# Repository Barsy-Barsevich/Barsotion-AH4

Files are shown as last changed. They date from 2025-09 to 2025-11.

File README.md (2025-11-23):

# AH4: ICM-45686 devboard
the 12th board after Berkut

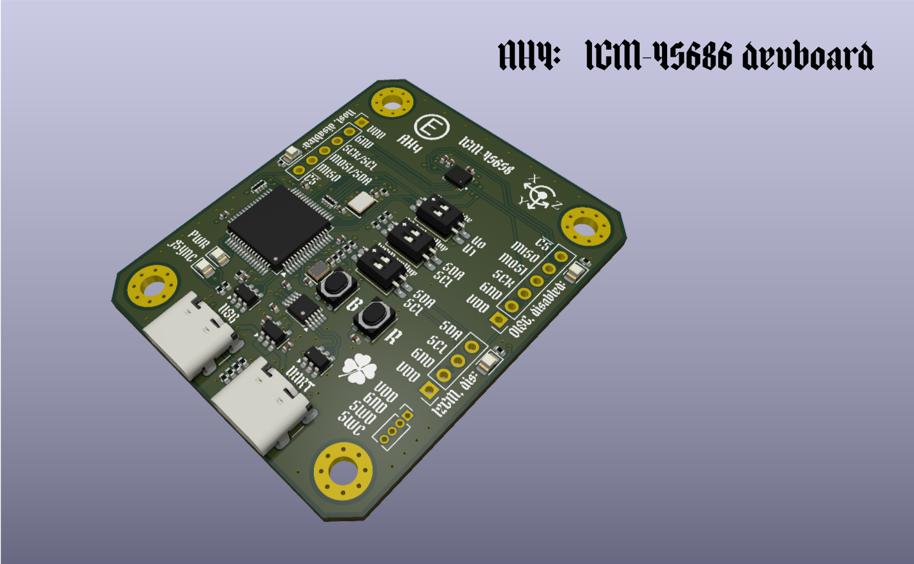
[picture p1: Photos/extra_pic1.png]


---
## ⚡️Abstract
Development board for ICM-45686 InvenSense TDK gyroscope & accelerometer. You can connect to it's interfaces (AP, OIS, I2CM) or drive them by on-board CH32V305RBT6 microcontroller.

- All ICM-45686 interfaces are routed (AP, OIS, I2CM);
- AP interface can be I2C or SPI
- On-board 32.768 kHz quartz oscillator to stabilize ODR frequency;
- On-board 32-bit RISC-V MCU to simplify ICM-45686 research;
- USB 2.0 HS and USB-UART are routed from the MCU.

---
## ⚡️Continious progress
- [Previous board: Barsotion-TA](https://github.com/Barsy-Barsevich/Barsotion-TA)
- [Previous board: Barsotion-PL1](https://github.com/Barsy-Barsevich/Barsotion-PL1)

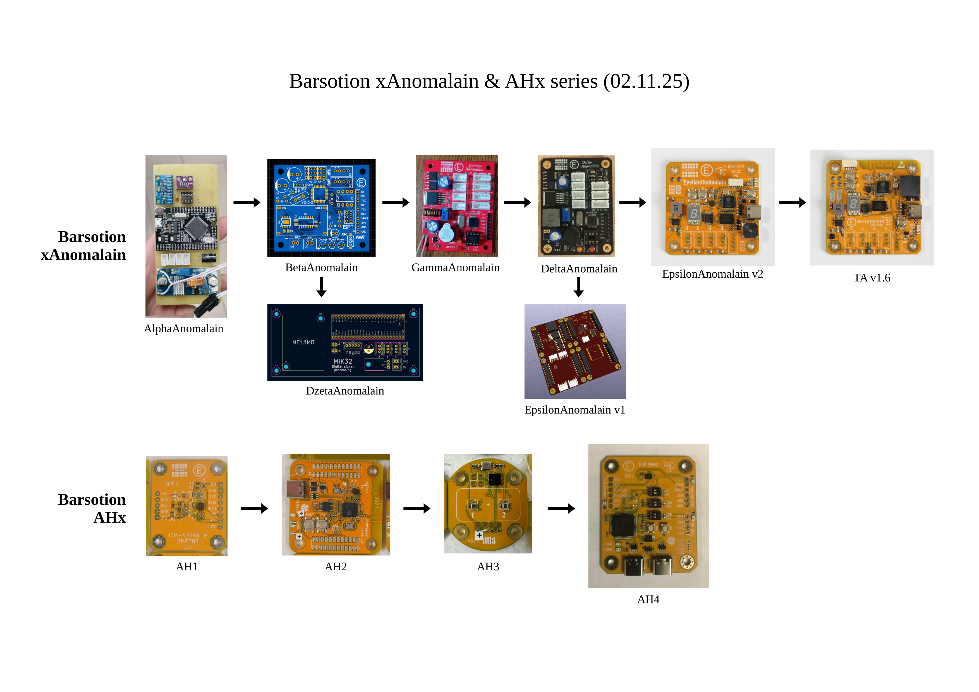
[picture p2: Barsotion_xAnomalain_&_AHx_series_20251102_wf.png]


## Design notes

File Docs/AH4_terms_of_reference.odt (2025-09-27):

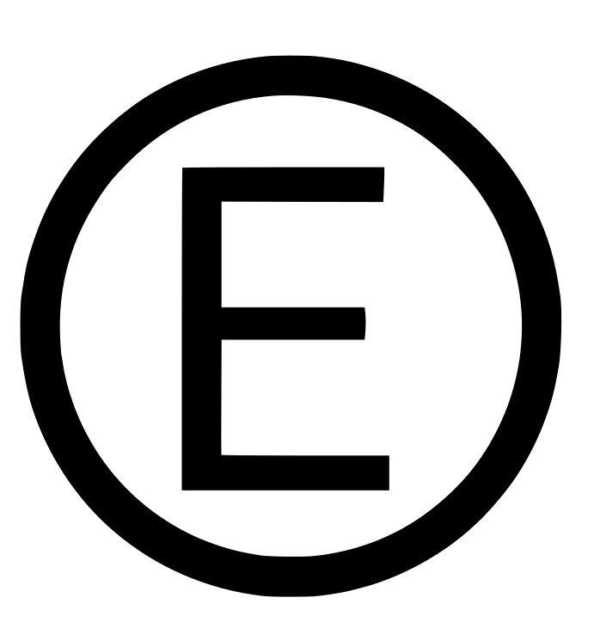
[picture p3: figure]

Barsotion AH4:

Terms of reference

## Abstract

This document is purposed to describe terms of reference of the perspective Barsotion development board AH4.

The AH4 (herein the board) is a project of development board for the TDK InvenSense ICM-45686, IMU (i.e. gyroscope & accelerometer) that has the best parameters in the world today, also allowing to measure linear accelerations up to 32g and angle velocities up to 4000 degrees per second.

The board is creating to develop ICM-45686 capabilities. It should contain the IMU & the microcontroller to research sensor features within one PCB.

## Main points

### The board should contain

- ICM-45686 IMU (gyroscope & accelerometer);
- Quartz oscillator 32-40 kHz for IMU ODR frequency stabilization;
- A modern 32-bit microcontroller at frequency not less than 100 MHz, having hardware floating-point unit (FPU) and USB 2.0 High-speed interface (supposedly CH32V305xxx);
- Reset button;
- 2x USB-C connector;
- “Tag-connect” connector for microcontroller flashing;
- USB-UART converter to link microcontroller even if USB-HS topology is failed;
- DIP-switch, 2 switches to lay 4 scenarios of working;
- 2 signal leds, yellow color, connected to DIP-switch;
- Power led, yellow color, to indicate powering;
- 3 signal leds, red color, connected to microcontroller;
- Signal led, yellow color, connected to microcontroller;
- Low-dropout (LDO) voltage regulator, 3.3V (supposedly AP2112-3.3).

### IMU connection

The ICM-45686 has three external interfaces:

- Host interface (SPI, I2C, I3C) to link with the microcontroller (host);
- Optical Image Stabilization Controller (OISC) interface (SPI);
- I2C master interface (I2CM).

The board should allow user to test all the ICM-45686 interfaces. According the datasheet, only one of OIS & I2CM interfaces can be used in moment. Supposedly the board schematic should link host & OIS interfaces directly to two hardware SPI ports of the microcontroller. Also, the host I2C interface should be connected to microcontroller’s I2C pins. Host interface (supporting SPI & I2C) should be routed to PLS connector. OIS and I2CM interfaces should be routed to individual PLS connectors.

The interrupt channels should be routed to the microcontroller.

The ODR syncronizing signal should be routed to the IMU pin via transistor controlled by microcontroller.

### PCB requirements

- The PCB should have at less 4 mounting holes;
- Should include designations for all the board connectors;
- The board silkscreen should contain warning that only one of OIS & I2CM interfaces can be activated at moment;
- Signal leds should indicate enabling microcontroller’s working with IMU host, OIS & I2CM interfaces.

## Revision history

Date | Modification
Aug 19, 2025 | Document’s first release.

Barsotion AH4: CONFIDENTIAL BARSOTIONTerms of reference

CONFIDENTIAL BARSOTION

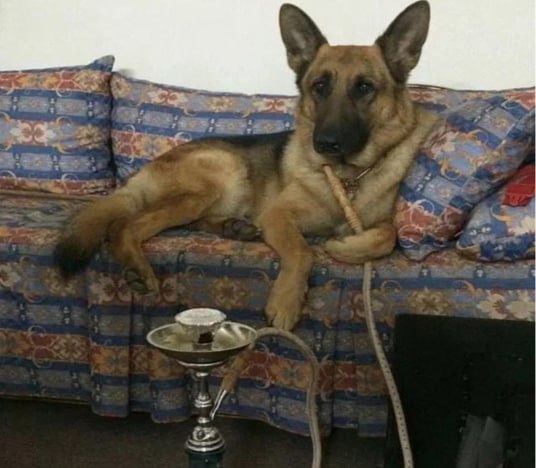
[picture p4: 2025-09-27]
totem.jpg

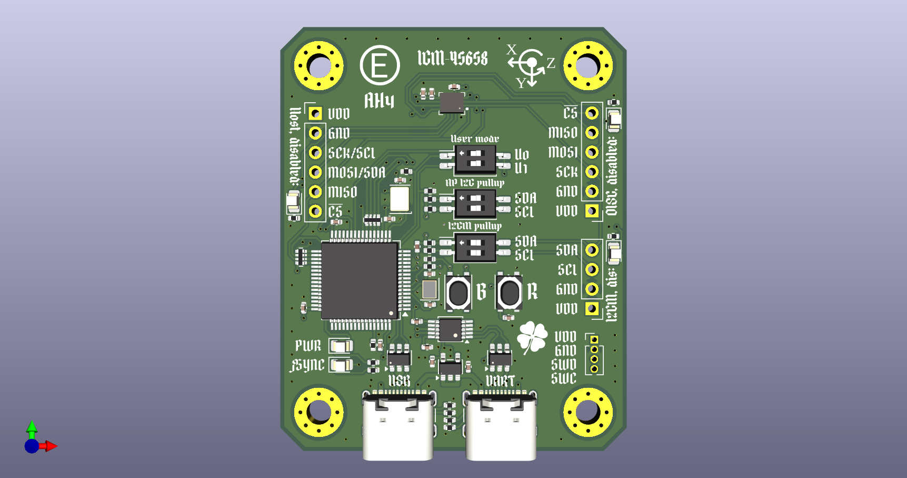
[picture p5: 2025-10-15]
Photos/AH4_pic5.png

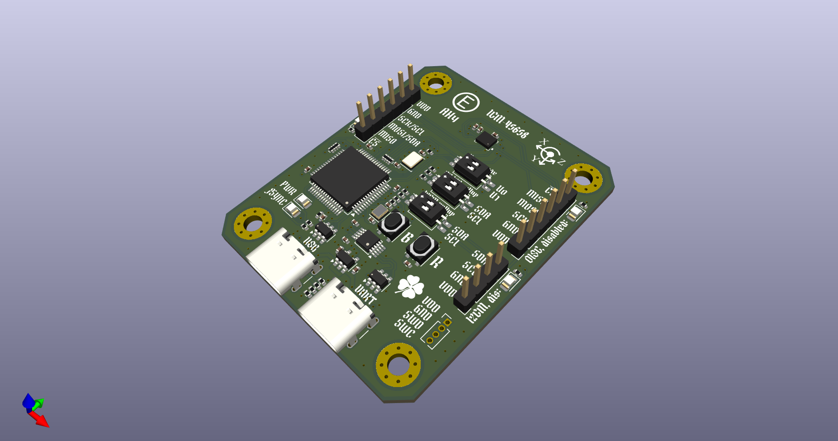
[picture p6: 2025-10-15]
Photos/AH4_pic1.png

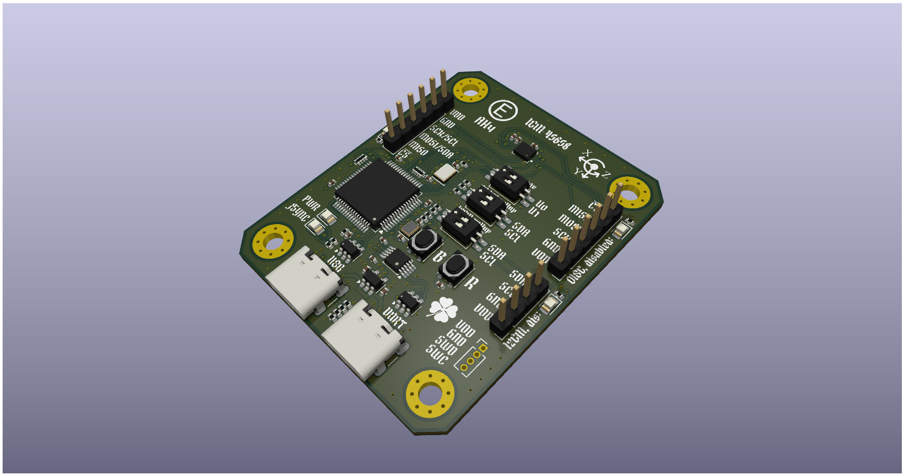
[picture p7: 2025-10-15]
Photos/AH4_pic3.png

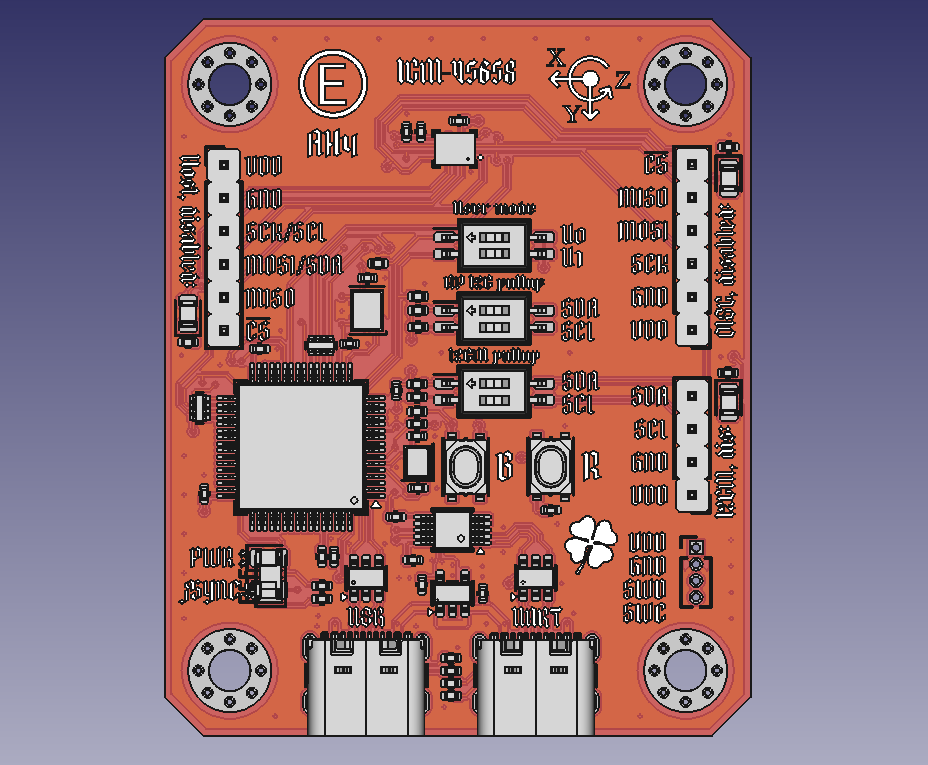
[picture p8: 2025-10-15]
Photos/Screenshot at 2025-10-15 00-12-45.png

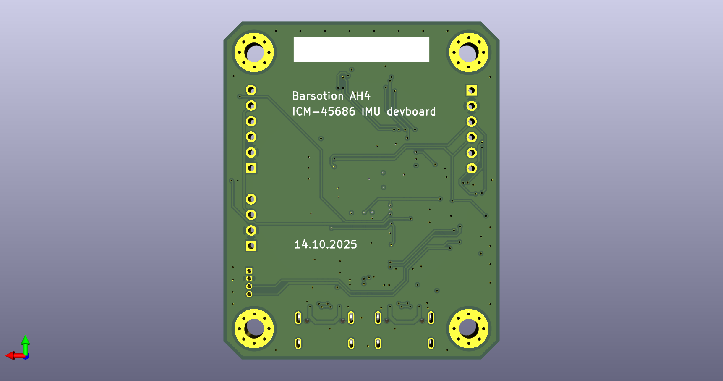
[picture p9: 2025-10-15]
Photos/AH4_pic6.png

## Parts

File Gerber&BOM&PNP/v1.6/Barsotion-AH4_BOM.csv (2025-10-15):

Reference | Value | Datasheet | Footprint | Qty | Mfr.Part | Description
C1,C2,C8,C9,C10,C11,C13,C14,C16 | 0.1uF | ~ | Capacitor_SMD:C_0402_1005Metric | 9 |  | Unpolarized capacitor
C3,C4,C12,C15 | 1uF | ~ | Capacitor_SMD:C_0402_1005Metric | 4 |  | Unpolarized capacitor
C5,C6,C7 | 12pF | ~ | Capacitor_SMD:C_0402_1005Metric | 3 |  | Unpolarized capacitor
D1,D2 | Yellow LED | ~ | LED_SMD:LED_0805_2012Metric | 2 |  | Light emitting diode, yellow 0805
D3,D4,D5 | Red LED | ~ | LED_SMD:LED_0805_2012Metric | 3 |  | Light emitting diode, red 0805
J1,J2 | USB_C_Receptacle_USB2.0_16P | https://www.usb.org/sites/default/files/documents/usb_type-c.zip | Connector_USB:USB_C_Receptacle_GCT_USB4105-xx-A_16P_TopMnt_Horizontal | 2 | TYPE C-DB-116PWB | USB 2.0-only 16P Type-C Receptacle connector
R1,R6,R7,R18 | 10k | ~ | Resistor_SMD:R_0402_1005Metric | 4 |  | Resistor
R2,R3,R4,R5,R12,R13,R14,R15 | 5.1k | ~ | Resistor_SMD:R_0402_1005Metric | 8 |  | Resistor
R8,R9,R10,R11,R16,R17 | 1k | ~ | Resistor_SMD:R_0402_1005Metric | 6 |  | Resistor
RN1,RN2 | 47 | ~ | Resistor_SMD:R_Array_Convex_4x0402 | 2 |  | 4 resistor network, parallel topology
SW1 | SW_DIP_x02 | ~ | Button_Switch_SMD:SW_DIP_SPSTx02_Slide_Copal_CHS-02B_W7.62mm_P1.27mm | 1 | CHS-02TB1 | 2x DIP Switch, Single Pole Single Throw (SPST) switch, small symbol
SW2 | SW_Push | ~ | Button_Switch_SMD:SW_Push_1P1T_NO_Vertical_Wuerth_434133025816 | 1 | TS3425BA | Push button switch, generic, two pins
SW3 | AP_I2C_R | ~ | Button_Switch_SMD:SW_DIP_SPSTx02_Slide_Copal_CHS-02B_W7.62mm_P1.27mm | 1 | CHS-02TB1 | 2x DIP Switch, Single Pole Single Throw (SPST) switch, small symbol
SW4 | I2CM_R | ~ | Button_Switch_SMD:SW_DIP_SPSTx02_Slide_Copal_CHS-02B_W7.62mm_P1.27mm | 1 | CHS-02TB1 | 2x DIP Switch, Single Pole Single Throw (SPST) switch, small symbol
SW5 | Boot | ~ | Button_Switch_SMD:SW_Push_1P1T_NO_Vertical_Wuerth_434133025816 | 1 | TS3425BA | Push button switch, generic, two pins
U1 | ICM-45686 |  | CustomPackage:ICM-45686 | 1 | ICM-45686 | Inertial measurement unit
U2 | CH32V305RBT6 |  | Package_QFP:LQFP-64_10x10mm_P0.5mm | 1 | CH32V305RBT6 | RISC-V WCH MCU
U3,U4 | USBLC6-2SC6 | https://www.st.com/resource/en/datasheet/usblc6-2.pdf | Package_TO_SOT_SMD:SOT-23-6 | 2 | USBLC6-2SC6 | Very low capacitance ESD protection diode, 2 data-line, SOT-23-6
U5 | CH340X | https://cdn.sparkfun.com/assets/5/0/a/8/5/CH340DS1.PDF | Package_SO:MSOP-10_3x3mm_P0.5mm | 1 | CH340X | USB serial converter, 5V-tolerant IO, UART, MSOP-10
U6 | AP2112K-3.3 | https://www.diodes.com/assets/Datasheets/AP2112.pdf | Package_TO_SOT_SMD:SOT-23-5 | 1 | AP2112K-3.3TRG1 | 600mA low dropout linear regulator, with enable pin, 3.8V-6V input voltage range, 3.3V fixed positive output, SOT-23-5
Y1 | Crystal_GND24 | ~ | Crystal:Crystal_SMD_2016-4Pin_2.0x1.6mm | 1 | XL7EL89COI-111YLC-16M | Four pin crystal, GND on pins 2 and 4
Y2 | Generator 32.768 kHz | http://cdn-reichelt.de/documents/datenblatt/B400/XO32.pdf | Oscillator:Oscillator_SMD_EuroQuartz_XO32-4Pin_3.2x2.5mm | 1 | OK7EL89CJI-111YLC-32.768K | HCMOS Clock Oscillator

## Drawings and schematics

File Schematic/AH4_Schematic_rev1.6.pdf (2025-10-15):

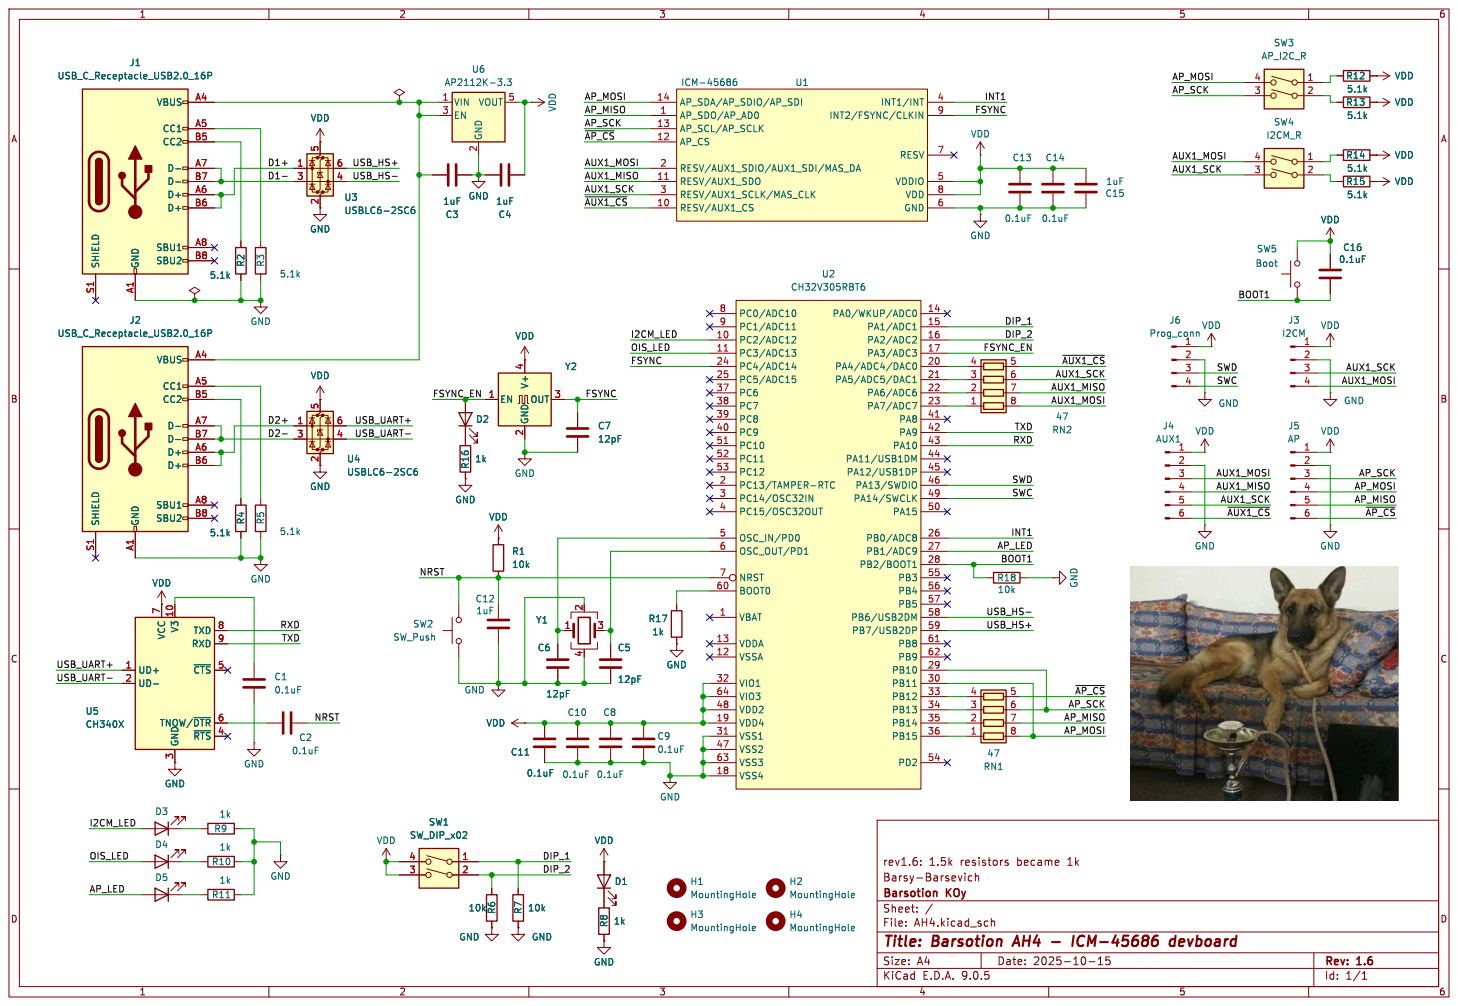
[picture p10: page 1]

3 TXD 8 RXD 9 ~{CTS}5 TNOW/~{DTR}6 ~{RTS}4 U5 CH340X

3 TXD 8 RXD 9 ~{CTS}5 TNOW/~{DTR}6 ~{RTS}4 GND

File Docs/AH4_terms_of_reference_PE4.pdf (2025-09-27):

## Barsotion AH4:

## Terms of reference

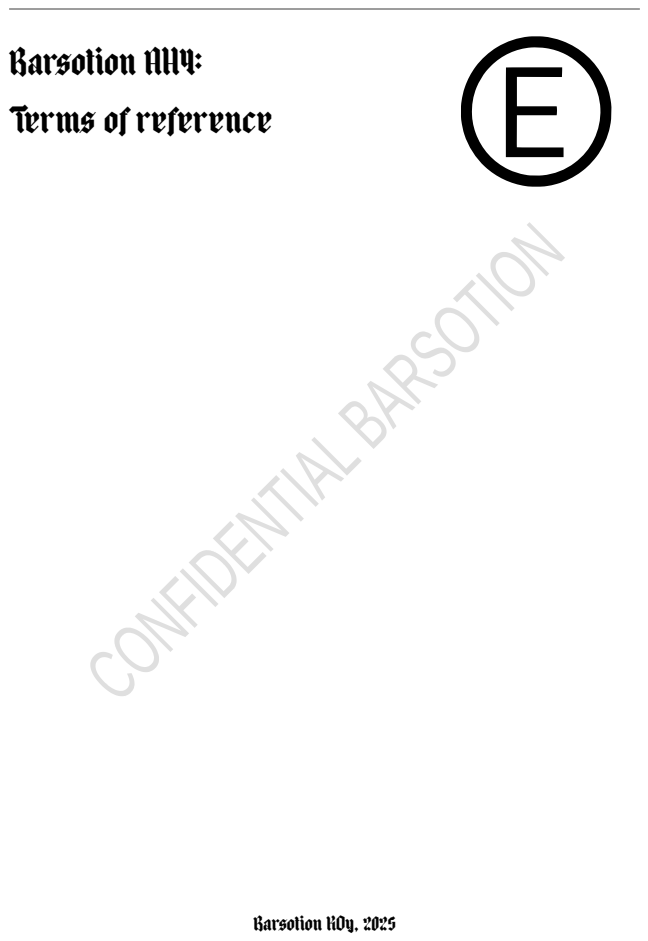
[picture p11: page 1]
Barsotion KOy, 2025

### Table of contents

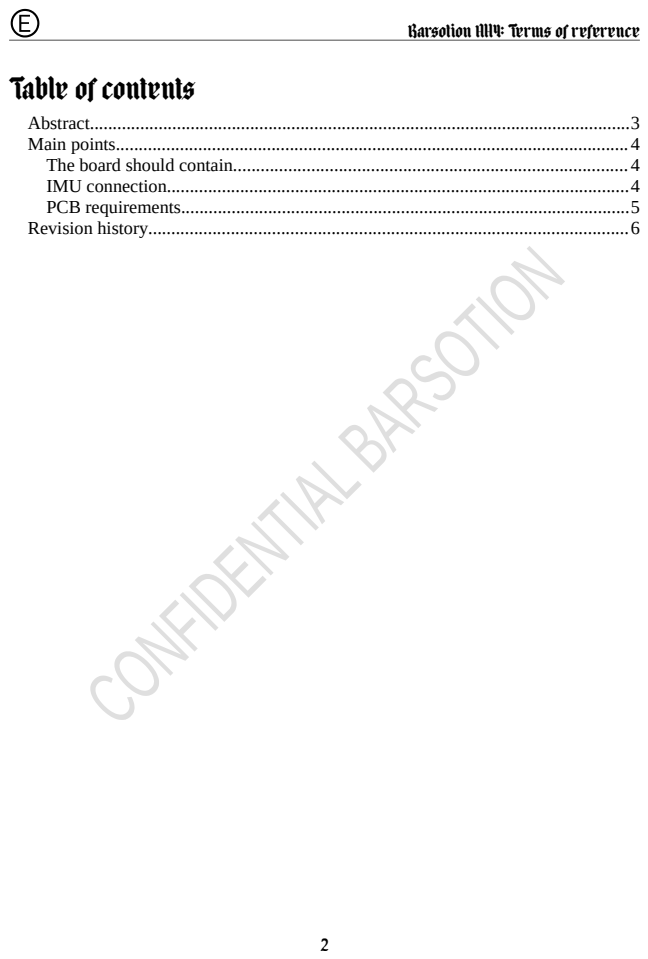
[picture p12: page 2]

Barsotion AH4: Terms of reference

Barsotion AH4: Terms of reference

### Abstract

This document is purposed to describe terms of reference of the perspective Barsotion development board AH4.
The AH4 (herein the board) is a project of development board for the TDK InvenSense ICM-45686, IMU (i.e. gyroscope & accelerometer) that has the best parameters in the world today, also allowing to measure linear accelerations up to 32g and angle velocities up to 4000 degrees per second.
The board is creating to develop ICM-45686 capabilities. It should contain the

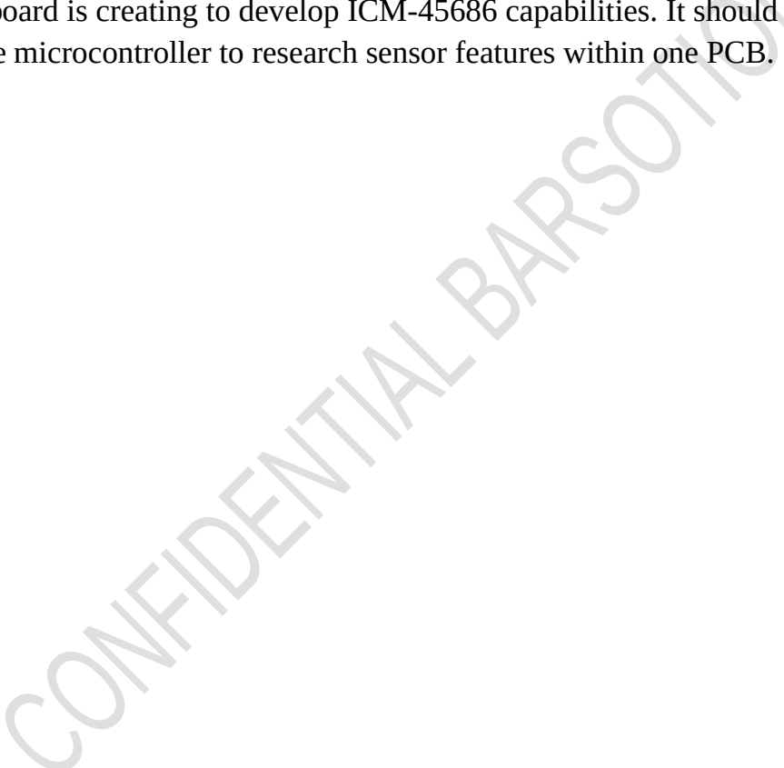
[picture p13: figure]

IMU & the microcontroller to research sensor features within one PCB.

3

Barsotion AH4: Terms of reference

### Main points

The board should contain
- ICM-45686 IMU (gyroscope & accelerometer);
- Quartz oscillator 32-40 kHz for IMU ODR frequency stabilization;
- A modern 32-bit microcontroller at frequency not less than 100 MHz, having hardware floating-point unit (FPU) and USB 2.0 High-speed interface (supposedly CH32V305xxx);
- 2x USB-C connector;
- “Tag-connect” connector for microcontroller flashing;
- USB-UART converter to link microcontroller even if USB-HS topology is failed;
- DIP-switch, 2 switches to lay 4 scenarios of working;
- 2 signal leds, yellow color, connected to DIP-switch;
- Power led, yellow color, to indicate powering;
- 3 signal leds, red color, connected to microcontroller;
- Signal led, yellow color, connected to microcontroller;
- Low-dropout (LDO) voltage regulator, 3.3V (supposedly AP2112-3.3).

IMU connection
The ICM-45686 has three external interfaces:
- Host interface (SPI, I2C, I3C) to link with the microcontroller (host);
- Optical Image Stabilization Controller (OISC) interface (SPI);
- I2C master interface (I2CM).
The board should allow user to test all the ICM-45686 interfaces. According the datasheet, only one of OIS & I2CM interfaces can be used in moment. Supposedly the board schematic should link host & OIS interfaces directly to two hardware SPI ports of the microcontroller. Also, the host I2C interface should be connected to

4

Barsotion AH4: Terms of reference

microcontroller’s I2C pins. Host interface (supporting SPI & I2C) should be routed to PLS connector. OIS and I2CM interfaces should be routed to individual PLS connectors.
The interrupt channels should be routed to the microcontroller.
The ODR syncronizing signal should be routed to the IMU pin via transistor controlled by microcontroller.

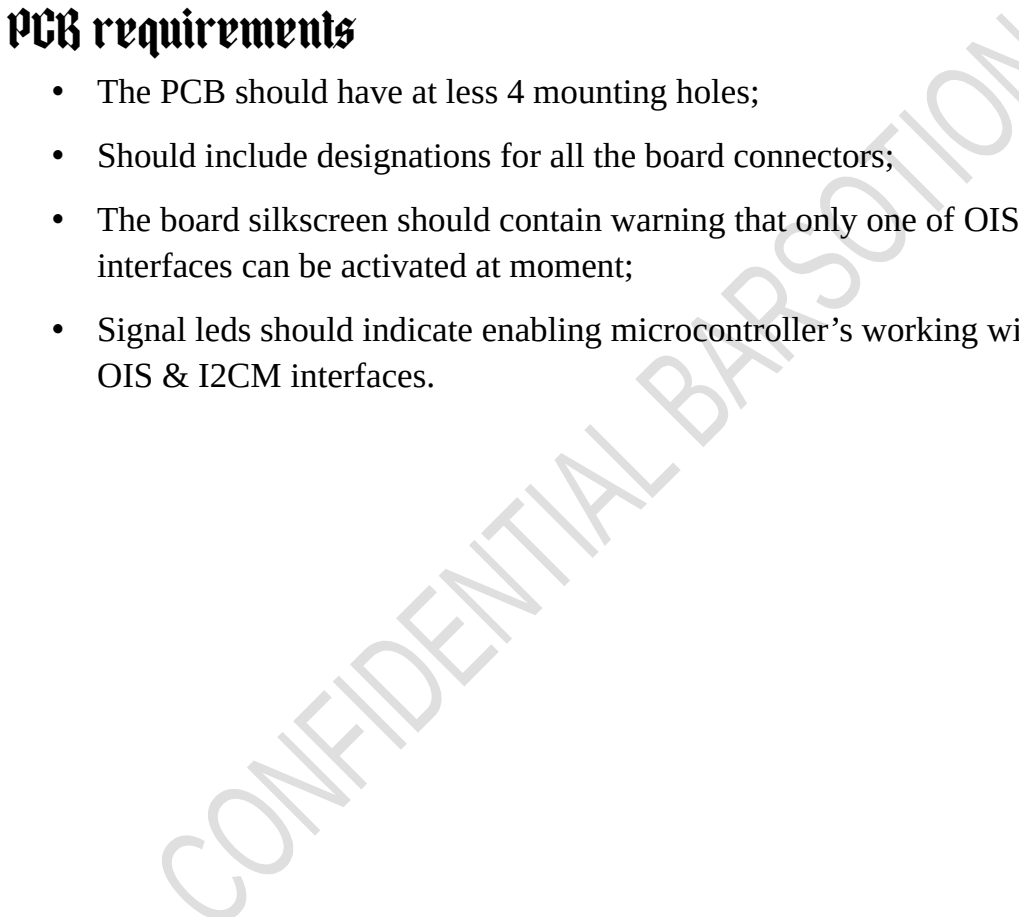
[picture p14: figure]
PCB requirements; interfaces can be activated at moment;; OIS & I2CM interfaces.

- The PCB should have at less 4 mounting holes;
- Should include designations for all the board connectors;
- The board silkscreen should contain warning that only one of OIS & I2CM
- Signal leds should indicate enabling microcontroller’s working with IMU host,

5

### Revision history

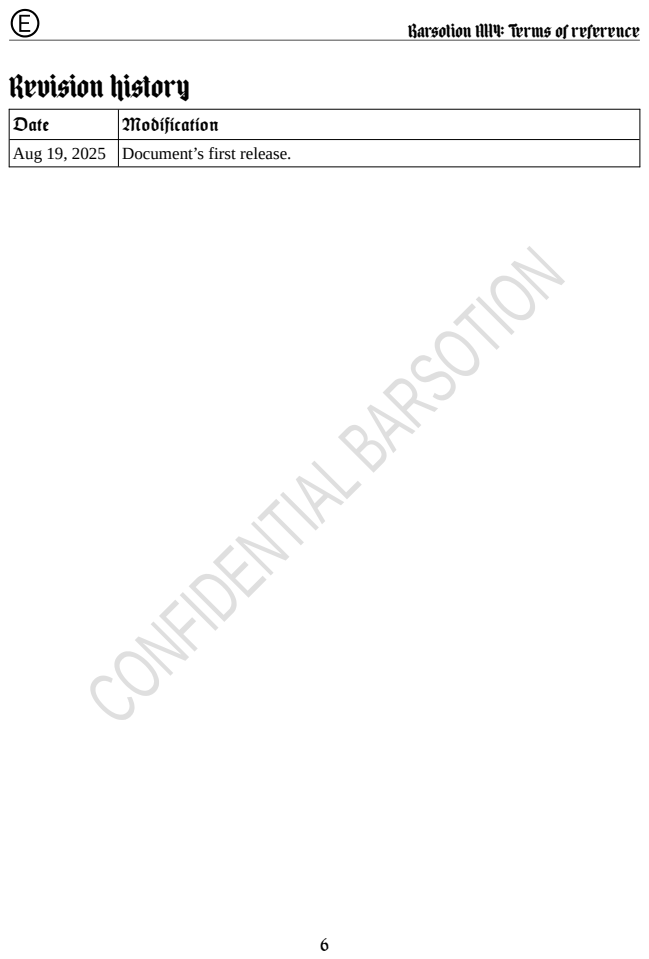
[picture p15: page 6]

Barsotion AH4: Terms of reference

Date | Modification
Aug 19, 2025 | Document’s first release.

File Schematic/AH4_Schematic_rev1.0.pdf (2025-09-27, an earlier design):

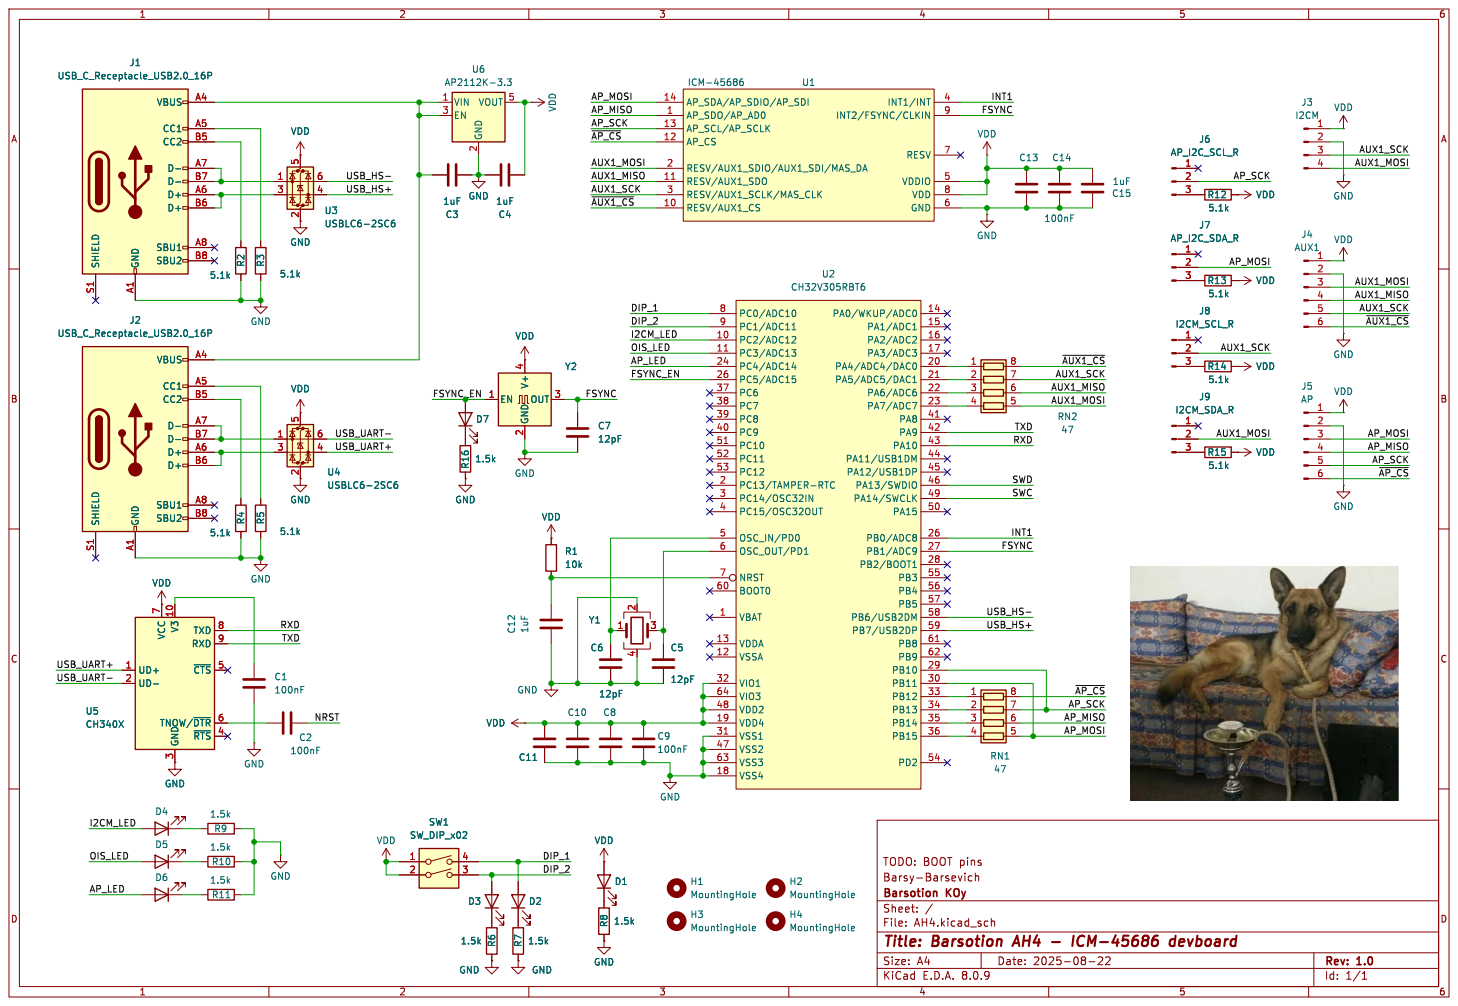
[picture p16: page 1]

2 EN 3 VOUT 5 U6 AP2112K-3.3 GND GND GND A1 VBUS A4 CC1 A5 D+ A6 D- A7 SBU1 A8 CC2 B5 D+ B6 D- B7 SBU2 B8 SHIELD S1

3 ~{RTS}4 ~{CTS}5 TNOW/~{DTR}6 VCC

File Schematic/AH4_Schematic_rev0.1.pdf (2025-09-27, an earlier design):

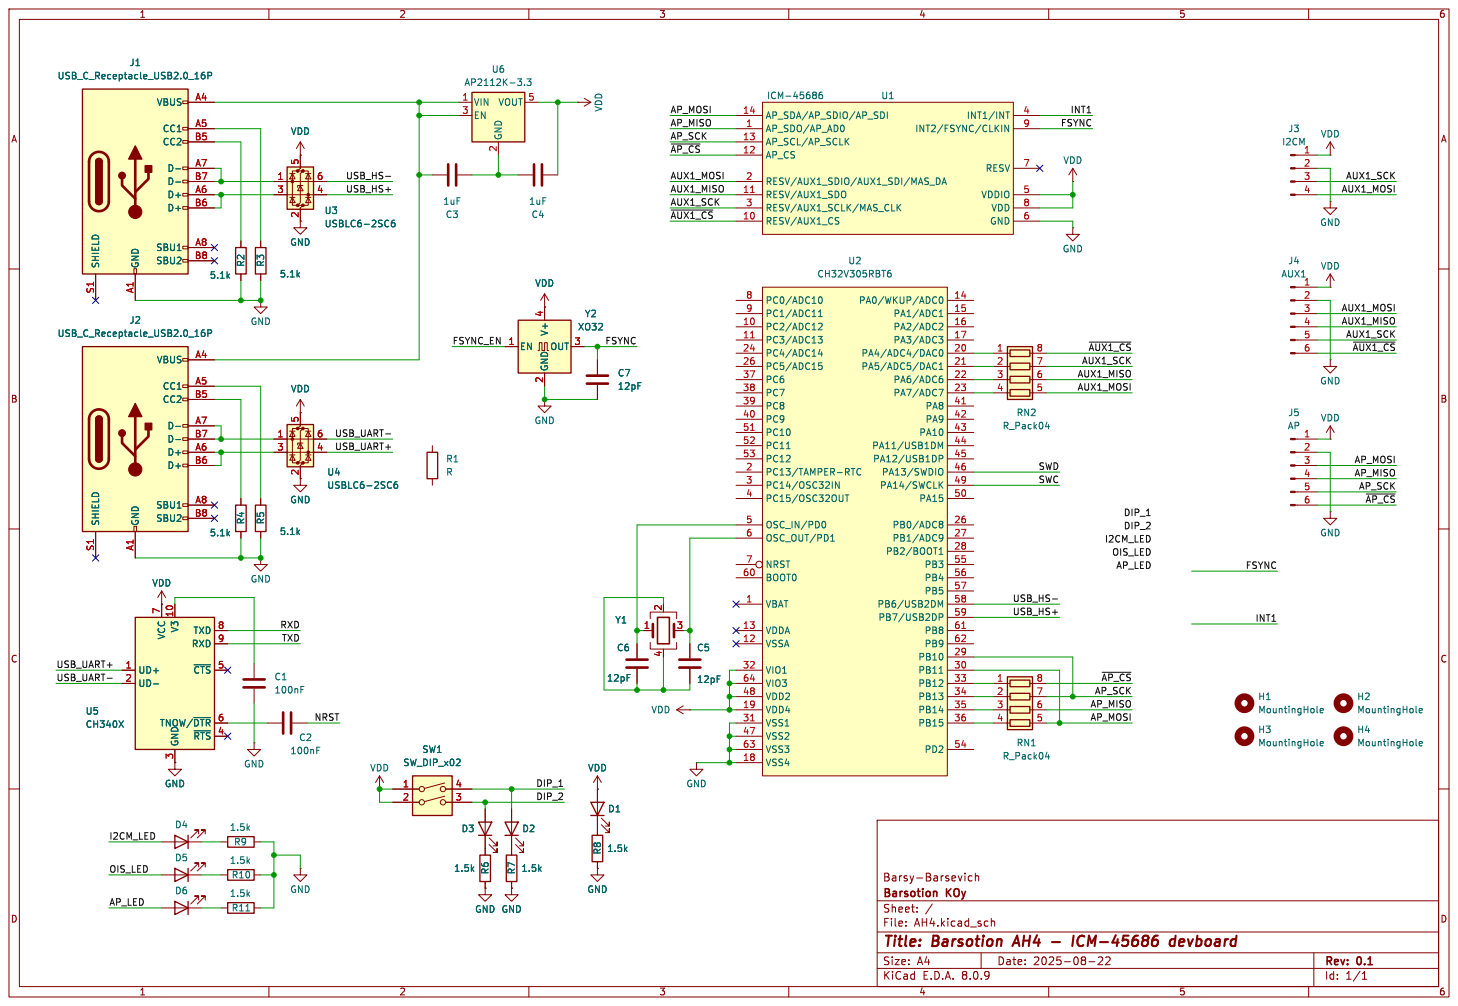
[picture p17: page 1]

3 ~{RTS}4 ~{CTS}5 TNOW/~{DTR}6 VCC

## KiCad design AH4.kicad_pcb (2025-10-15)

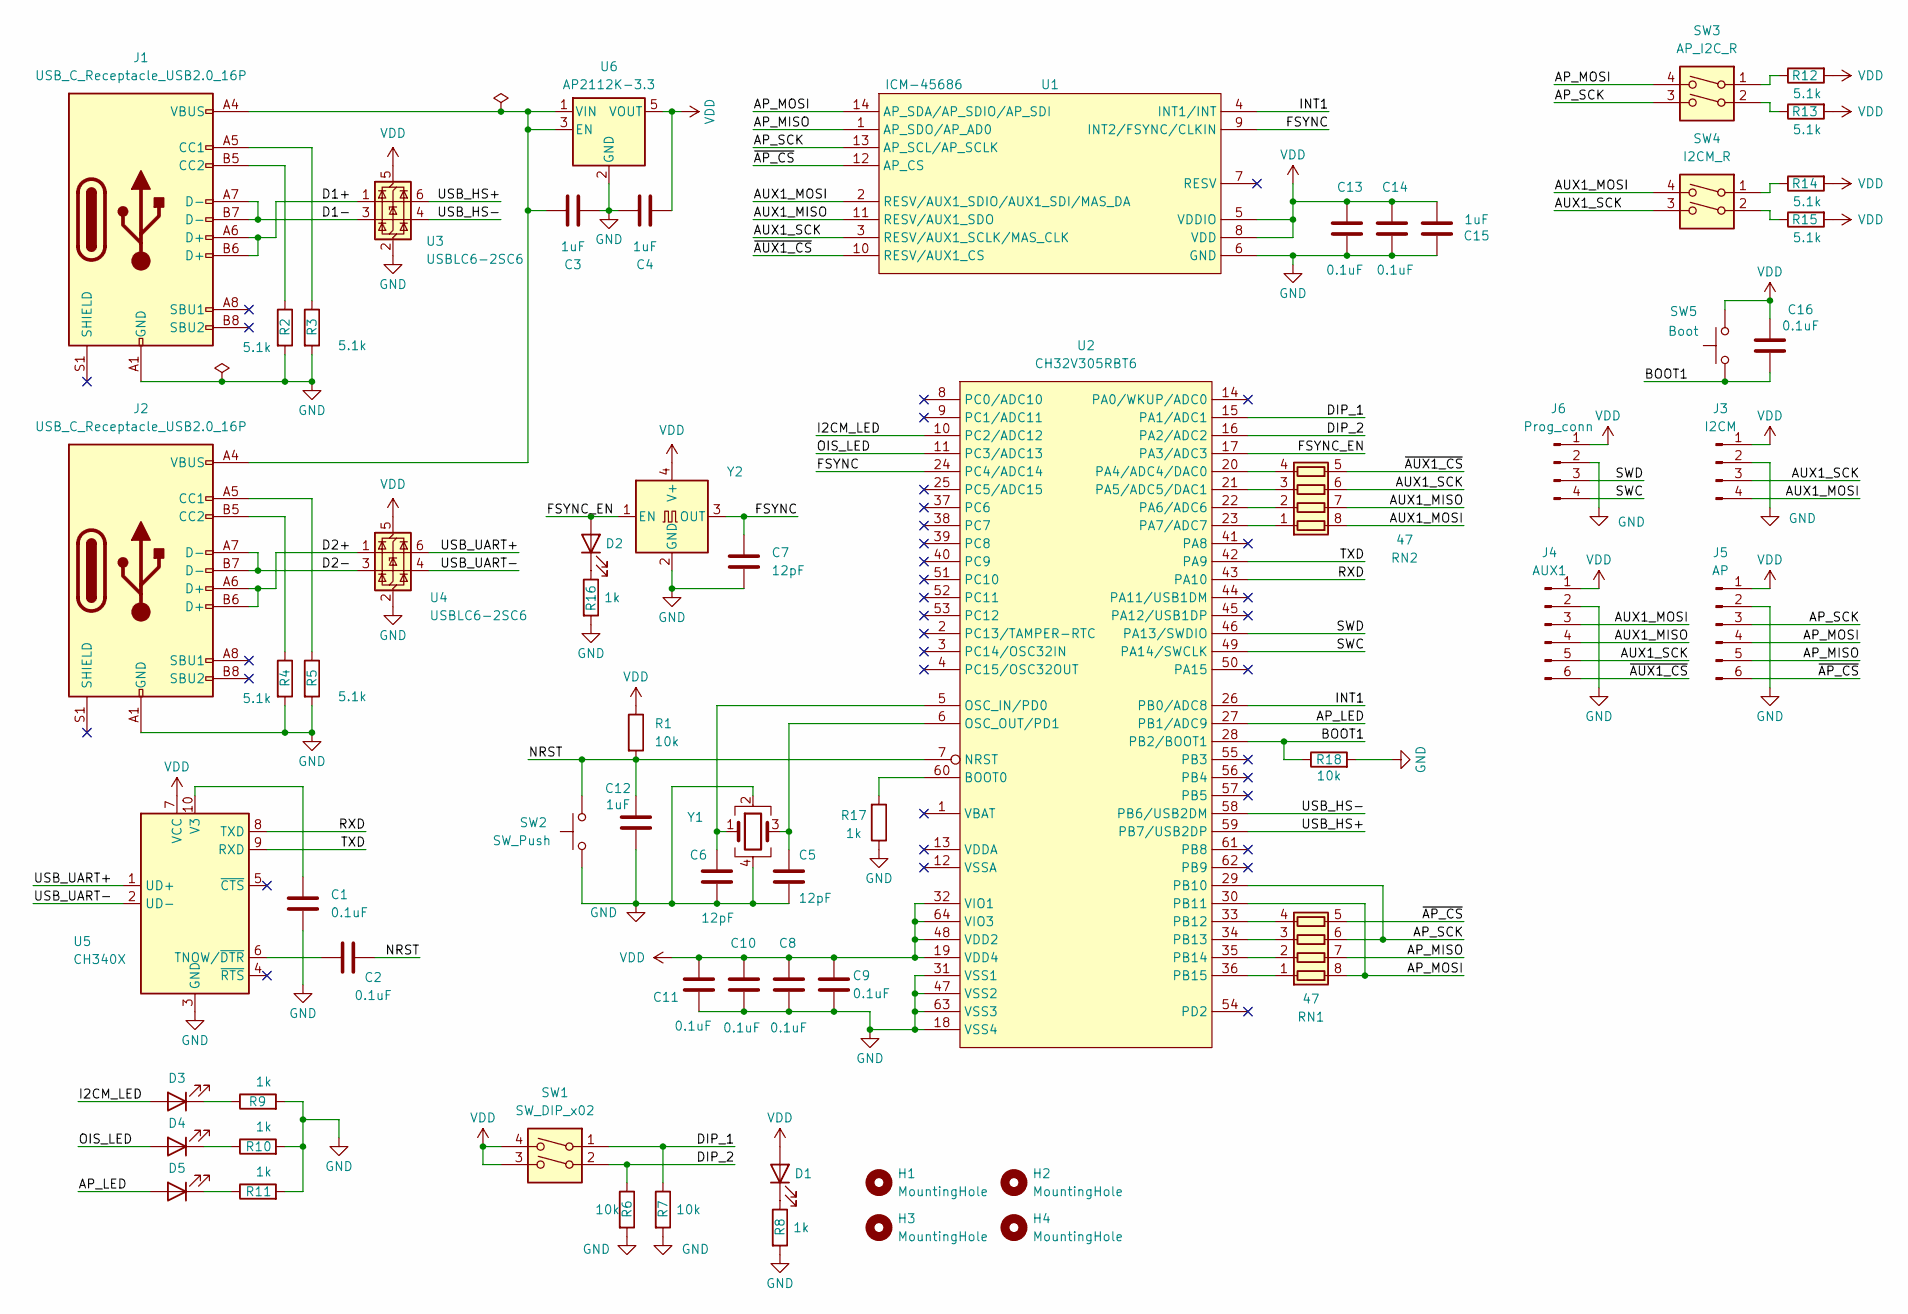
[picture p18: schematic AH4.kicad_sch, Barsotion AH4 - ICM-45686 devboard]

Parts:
C1, C2, C8, C9, C10, C11, C13, C14, C16: 0.1uF; C_0402_1005Metric
C3, C4, C12, C15: 1uF; C_0402_1005Metric
C5, C6, C7: 12pF; C_0402_1005Metric
D1, D2: Yellow LED; LED_0805_2012Metric
D3, D4, D5: Red LED; LED_0805_2012Metric
H1, H2, H3, H4: MountingHole; MountingHole_3.2mm_M3_Pad_Via
J1, J2: USB_C_Receptacle_USB2.0_16P; USB_C_Receptacle_GCT_USB4105-xx-A_16P_TopMnt_Horizontal; Mfr.Part TYPE C-DB-116PWB
J3: I2CM; PinHeader_1x04_P2.54mm_Vertical
J4: AUX1; PinHeader_1x06_P2.54mm_Vertical
J5: AP; PinHeader_1x06_P2.54mm_Vertical
J6: Prog_conn; PinHeader_1x04_P1.27mm_Vertical
R1, R6, R7, R18: 10k; R_0402_1005Metric
R2, R3, R4, R5, R12, R13, R14, R15: 5.1k; R_0402_1005Metric
R8, R9, R10, R11, R16, R17: 1k; R_0402_1005Metric
RN1, RN2: 47; R_Array_Convex_4x0402
SW1: SW_DIP_x02; SW_DIP_SPSTx02_Slide_Copal_CHS-02B_W7.62mm_P1.27mm; Mfr.Part CHS-02TB1
SW2: SW_Push; SW_Push_1P1T_NO_Vertical_Wuerth_434133025816; Mfr.Part TS3425BA
SW3: AP_I2C_R; SW_DIP_SPSTx02_Slide_Copal_CHS-02B_W7.62mm_P1.27mm; Mfr.Part CHS-02TB1
SW4: I2CM_R; SW_DIP_SPSTx02_Slide_Copal_CHS-02B_W7.62mm_P1.27mm; Mfr.Part CHS-02TB1
SW5: Boot; SW_Push_1P1T_NO_Vertical_Wuerth_434133025816; Mfr.Part TS3425BA
U1: ICM-45686; Mfr.Part ICM-45686
U2: CH32V305RBT6; LQFP-64_10x10mm_P0.5mm; Mfr.Part CH32V305RBT6
U3, U4: USBLC6-2SC6; SOT-23-6; Mfr.Part USBLC6-2SC6
U5: CH340X; MSOP-10_3x3mm_P0.5mm; Mfr.Part CH340X
U6: AP2112K-3.3; SOT-23-5; Mfr.Part AP2112K-3.3TRG1
Y1: Crystal_GND24; Crystal_SMD_2016-4Pin_2.0x1.6mm; Mfr.Part XL7EL89COI-111YLC-16M
Y2: Generator 32.768 kHz; Oscillator_SMD_EuroQuartz_XO32-4Pin_3.2x2.5mm; Mfr.Part OK7EL89CJI-111YLC-32.768K

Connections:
/AP_LED: D5.2 (A), U2.27 (PB1/ADC9)
/AP_MISO: J5.5, RN1.7 (R2.2), U1.1 (AP_SDO/AP_AD0)
/AP_MOSI: J5.4, RN1.8 (R1.2), SW3.4, U1.14 (AP_SDA/AP_SDIO/AP_SDI), U2.30 (PB11)
/AP_SCK: J5.3, RN1.6 (R3.2), SW3.3, U1.13 (AP_SCL/AP_SCLK), U2.29 (PB10)
/AUX1_MISO: J4.4, RN2.7 (R2.2), U1.11 (RESV/AUX1_SDO)
/AUX1_MOSI: J3.4, J4.3, RN2.8 (R1.2), SW4.4, U1.2 (RESV/AUX1_SDIO/AUX1_SDI/MAS_DA)
/AUX1_SCK: J3.3, J4.5, RN2.6 (R3.2), SW4.3, U1.3 (RESV/AUX1_SCLK/MAS_CLK)
/BOOT1: C16.2, R18.1, SW5.1, U2.28 (PB2/BOOT1)
/D1+: J1.A6 (D+), J1.B6 (D+), U3.1 (I/O1)
/D1-: J1.A7 (D-), J1.B7 (D-), U3.3 (I/O2)
/D2+: J2.A6 (D+), J2.B6 (D+), U4.1 (I/O1)
/D2-: J2.A7 (D-), J2.B7 (D-), U4.3 (I/O2)
/DIP_1: R7.1, SW1.1, U2.15 (PA1/ADC1)
/DIP_2: R6.1, SW1.2, U2.16 (PA2/ADC2)
/FSYNC: C7.1, U1.9 (INT2/FSYNC/CLKIN), U2.24 (PC4/ADC14), Y2.3 (OUT)
/FSYNC_EN: D2.2 (A), U2.17 (PA3/ADC3), Y2.1 (EN)
/I2CM_LED: D3.2 (A), U2.10 (PC2/ADC12)
/INT1: U1.4 (INT1/INT), U2.26 (PB0/ADC8)
/NRST: C2.2, C12.1, R1.2, SW2.2, U2.7 (NRST)
/OIS_LED: D4.2 (A), U2.11 (PC3/ADC13)
/RXD: U2.43 (PA10), U5.8 (TXD)
/SWC: J6.4, U2.49 (PA14/SWCLK)
/SWD: J6.3, U2.46 (PA13/SWDIO)
/TXD: U2.42 (PA9), U5.9 (RXD)
/USB_HS+: U2.59 (PB7/USB2DP), U3.6 (I/O1)
/USB_HS-: U2.58 (PB6/USB2DM), U3.4 (I/O2)
/USB_UART+: U4.6 (I/O1), U5.1 (UD+)
/USB_UART-: U4.4 (I/O2), U5.2 (UD-)
/~AP_CS: J5.6, RN1.5 (R4.2), U1.12 (AP_CS)
/~AUX1_CS: J4.6, RN2.5 (R4.2), U1.10 (RESV/AUX1_CS)
GND: C1.2, C3.2, C4.1, C5.2, C6.2, C7.2, C8.2, C9.2, C10.2, C11.2, C12.2, C13.2, C14.2, C15.1, J1.A1 (GND), J1.A12 (GND), J1.B1 (GND), J1.B12 (GND), J2.A1 (GND), J2.A12 (GND), J2.B1 (GND), J2.B12 (GND), J3.2, J4.2, J5.2, J6.2, R2.2, R3.2, R4.2, R5.2, R6.2, R7.2, R8.2, R9.2, R10.2, R11.2, R16.2, R17.1, R18.2, SW2.1, U1.6 (GND), U2.18 (VSS4), U2.31 (VSS1), U2.47 (VSS2), U2.63 (VSS3), U3.2 (GND), U4.2 (GND), U5.3 (GND), U6.2 (GND), Y1.2, Y1.4, Y2.2 (GND)
unnamed: D1.1 (K), R8.1
unnamed: D2.1 (K), R16.1
unnamed: D3.1 (K), R9.1
unnamed: D4.1 (K), R10.1
unnamed: D5.1 (K), R11.1
unnamed: J1.A5 (CC1), R3.1
unnamed: J1.B5 (CC2), R2.1
unnamed: J2.A5 (CC1), R5.1
unnamed: J2.B5 (CC2), R4.1
unnamed: R12.1, SW3.1
unnamed: R13.1, SW3.2
unnamed: R14.1, SW4.1
unnamed: R15.1, SW4.2
unnamed: RN1.1 (R1.1), U2.36 (PB15)
unnamed: RN1.2 (R2.1), U2.35 (PB14)
unnamed: RN1.3 (R3.1), U2.34 (PB13)
unnamed: RN1.4 (R4.1), U2.33 (PB12)
unnamed: RN2.1 (R1.1), U2.23 (PA7/ADC7)
unnamed: RN2.2 (R2.1), U2.22 (PA6/ADC6)
unnamed: RN2.3 (R3.1), U2.21 (PA5/ADC5/DAC1)
unnamed: RN2.4 (R4.1), U2.20 (PA4/ADC4/DAC0)
unnamed: R17.2, U2.60 (BOOT0)
unnamed: C6.1, U2.5 (OSC_IN/PD0), Y1.1
unnamed: C5.1, U2.6 (OSC_OUT/PD1), Y1.3
unnamed: C2.1, U5.6 (TNOW/~DTR)
unnamed: C1.1, U5.10 (V3)
unnamed: C3.1, J1.A4 (VBUS), J1.A9 (VBUS), J1.B4 (VBUS), J1.B9 (VBUS), J2.A4 (VBUS), J2.A9 (VBUS), J2.B4 (VBUS), J2.B9 (VBUS), U6.1 (VIN), U6.3 (EN)
VDD: C4.2, C8.1, C9.1, C10.1, C11.1, C13.1, C14.1, C15.2, C16.1, D1.2 (A), J3.1, J4.1, J5.1, J6.1, R1.1, R12.2, R13.2, R14.2, R15.2, SW1.3, SW1.4, SW5.2, U1.5 (VDDIO), U1.8 (VDD), U2.19 (VDD4), U2.32 (VIO1), U2.48 (VDD2), U2.64 (VIO3), U3.5 (VBUS), U4.5 (VBUS), U5.7 (VCC), U6.5 (VOUT), Y2.4 (V+)

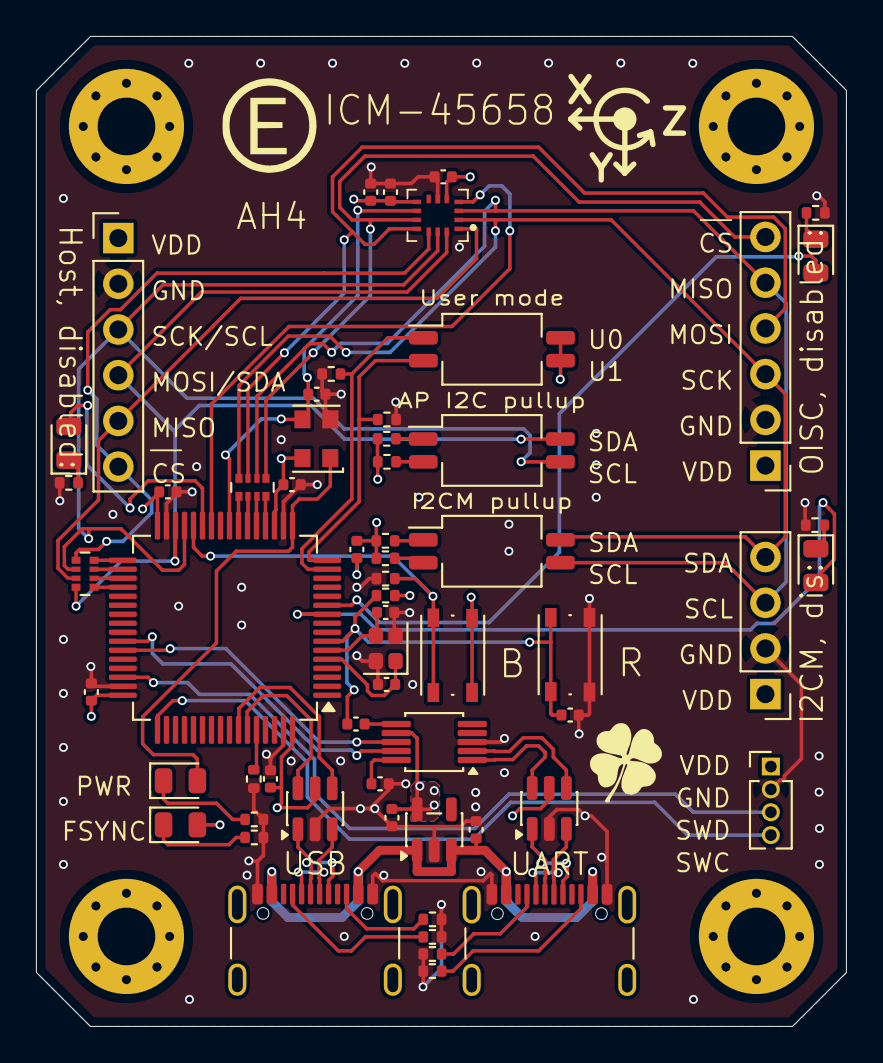
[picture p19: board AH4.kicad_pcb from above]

Board: 4 copper layers, 45.0 x 55.0 mm, 64 parts (0 on the bottom side), 59 nets.

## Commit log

2025-09-27 all kicad files included
    [AH4.kicad_pcb, AH4.kicad_sch]
2025-09-29 add kicad_prl & _pro files
2025-10-13 update, the board done
    [AH4.kicad_pcb]
2025-10-14 update & gerber
    [AH4-B_Cu.gbr, AH4-B_Mask.gbr, AH4-B_Paste.gbr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]
